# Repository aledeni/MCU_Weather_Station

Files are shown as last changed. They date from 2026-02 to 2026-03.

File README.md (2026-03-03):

# MCU Weather Station

The heart of the board is the ATmega328P microcontroller, it also features a 6-pin AVR-ISP connector for burning the bootloader and a USB connector with serial driver for programming the microcontroller. For connectivity, an ESP8266 Wi-Fi module is provided, connected to the ATmega328P.
The boards were ordered from China via the JLCPCB website (5 pcs at a cost of 31 EUR) and the components will be assembled and soldered by myself.
The board schematic can be found in schematic/MCU_Weather_Station.pdf from this git repository.

__Why this board?__

The purpose of the board is to provide a simple but practical example of an online weather station that will use the api.open-meteo.com server for web requests, weather information such as temperature, humidity and time zone will be shown on the OLED display. I will develop the firmware using Arduino IDE.

__PCB view:__

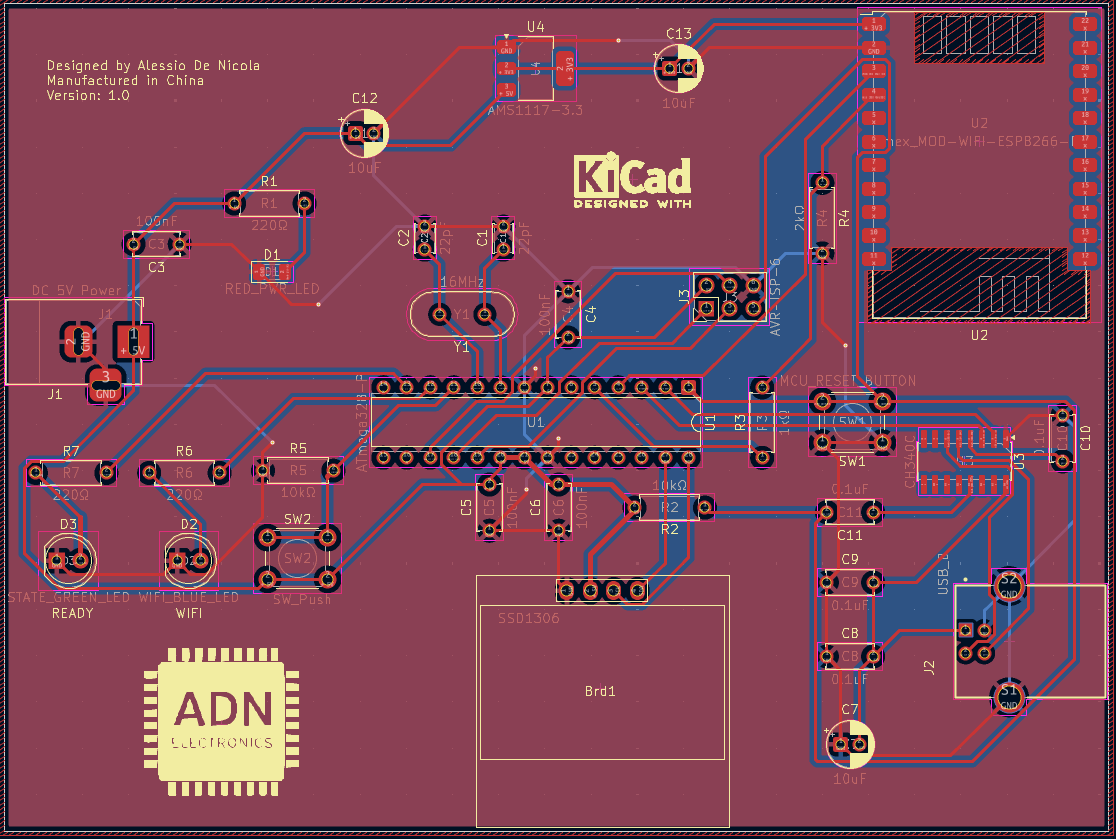
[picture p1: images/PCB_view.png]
PCB view


__3D view:__

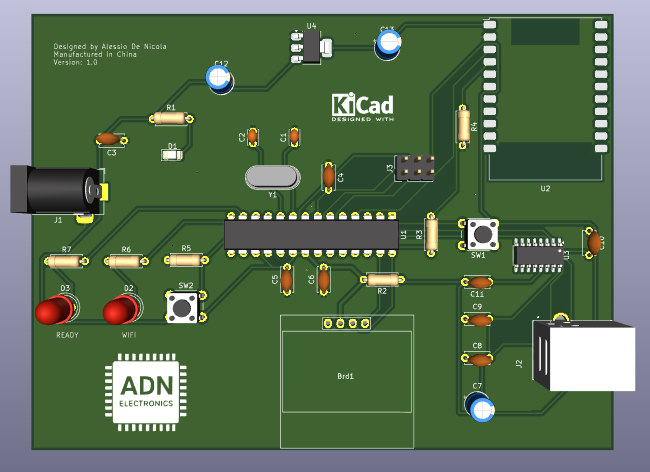
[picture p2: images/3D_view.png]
3D view


__Components:__

- 1x ATmega328P DIP-28
- 1x CH340C serial driver SMD
- 1x ESP8266 Olimex_MOD-WIFI-ESP8266-DEV module
- 1x OLED 128x64 SSD1306 display
- 1x AMS1117 voltage regulator (from 5V to 3.3V)
- 1x USB-B THT connector
- 1x DC Barrel Jack 5V THT
- 1x 16 MHz crystal
- 1x 5mm blue LED
- 1x 5mm green LED
- 1x SMD red power LED
- 2x 6mm THT push buttons
- 1x 2x3 AVR-ISP header
- 7x Resistors THT (3x 220Ω | 2x 10kΩ | 1x 1kΩ | 1x 2kΩ)
- 8x 100nF (0.1uF) ceramic capacitors THT
- 2x 22pF ceramic capacitors THT
- 3x 10uF electrolytic radial capacitors THT

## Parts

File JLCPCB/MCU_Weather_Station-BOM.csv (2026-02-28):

Id | Designator | Footprint | Quantity | Designation | Supplier and ref
1 | C6,C3,C5,C4 | C_Disc_D5.0mm_W2.5mm_P5.00mm | 4 | 100nF
2 | C10,C11,C8,C9 | C_Disc_D5.0mm_W2.5mm_P5.00mm | 4 | 0.1uF
3 | SW1 | SW_PUSH_6mm | 1 | MCU_RESET_BUTTON
4 | J3 | PinHeader_2x03_P2.54mm_Vertical | 1 | AVR-ISP-6
5 | D2 | LED_D5.0mm | 1 | WIFI_BLUE_LED
6 | U3 | SOIC-16_3.9x9.9mm_P1.27mm | 1 | CH340C
7 | R7,R1,R6 | R_Axial_DIN0207_L6.3mm_D2.5mm_P7.62mm_Horizontal | 3 | 220Ω
8 | C13,C7,C12 | CP_Radial_D5.0mm_P2.00mm | 3 | 10uF
9 | U2 | Olimex_MOD-WIFI-ESP8266-DEV | 1 | Olimex_MOD-WIFI-ESP8266-DEV
10 | R2,R5 | R_Axial_DIN0207_L6.3mm_D2.5mm_P7.62mm_Horizontal | 2 | 10kΩ
11 | U1 | DIP-28_W7.62mm | 1 | ATmega328-P
12 | D3 | LED_D5.0mm | 1 | STATE_GREEN_LED
13 | J2 | SAMTEC_USB-B-S-X-X-TH | 1 | USB_B
14 | Y1 | Crystal_HC49-4H_Vertical | 1 | 16MHz
15 | Brd1 | 128x64OLED | 1 | SSD1306
16 | R3 | R_Axial_DIN0207_L6.3mm_D2.5mm_P7.62mm_Horizontal | 1 | 1kΩ
17 | C2,C1 | C_Disc_D3.0mm_W2.0mm_P2.50mm | 2 | 22pF
18 | R4 | R_Axial_DIN0207_L6.3mm_D2.5mm_P7.62mm_Horizontal | 1 | 2kΩ
19 | SW2 | SW_PUSH_6mm | 1 | SW_Push
20 | J1 | BarrelJack_Horizontal | 1 | DC 5V Power
21 | D1 | LED_1206_3216Metric | 1 | RED_PWR_LED
22 | U4 | SOT-223-3_TabPin2 | 1 | AMS1117-3.3

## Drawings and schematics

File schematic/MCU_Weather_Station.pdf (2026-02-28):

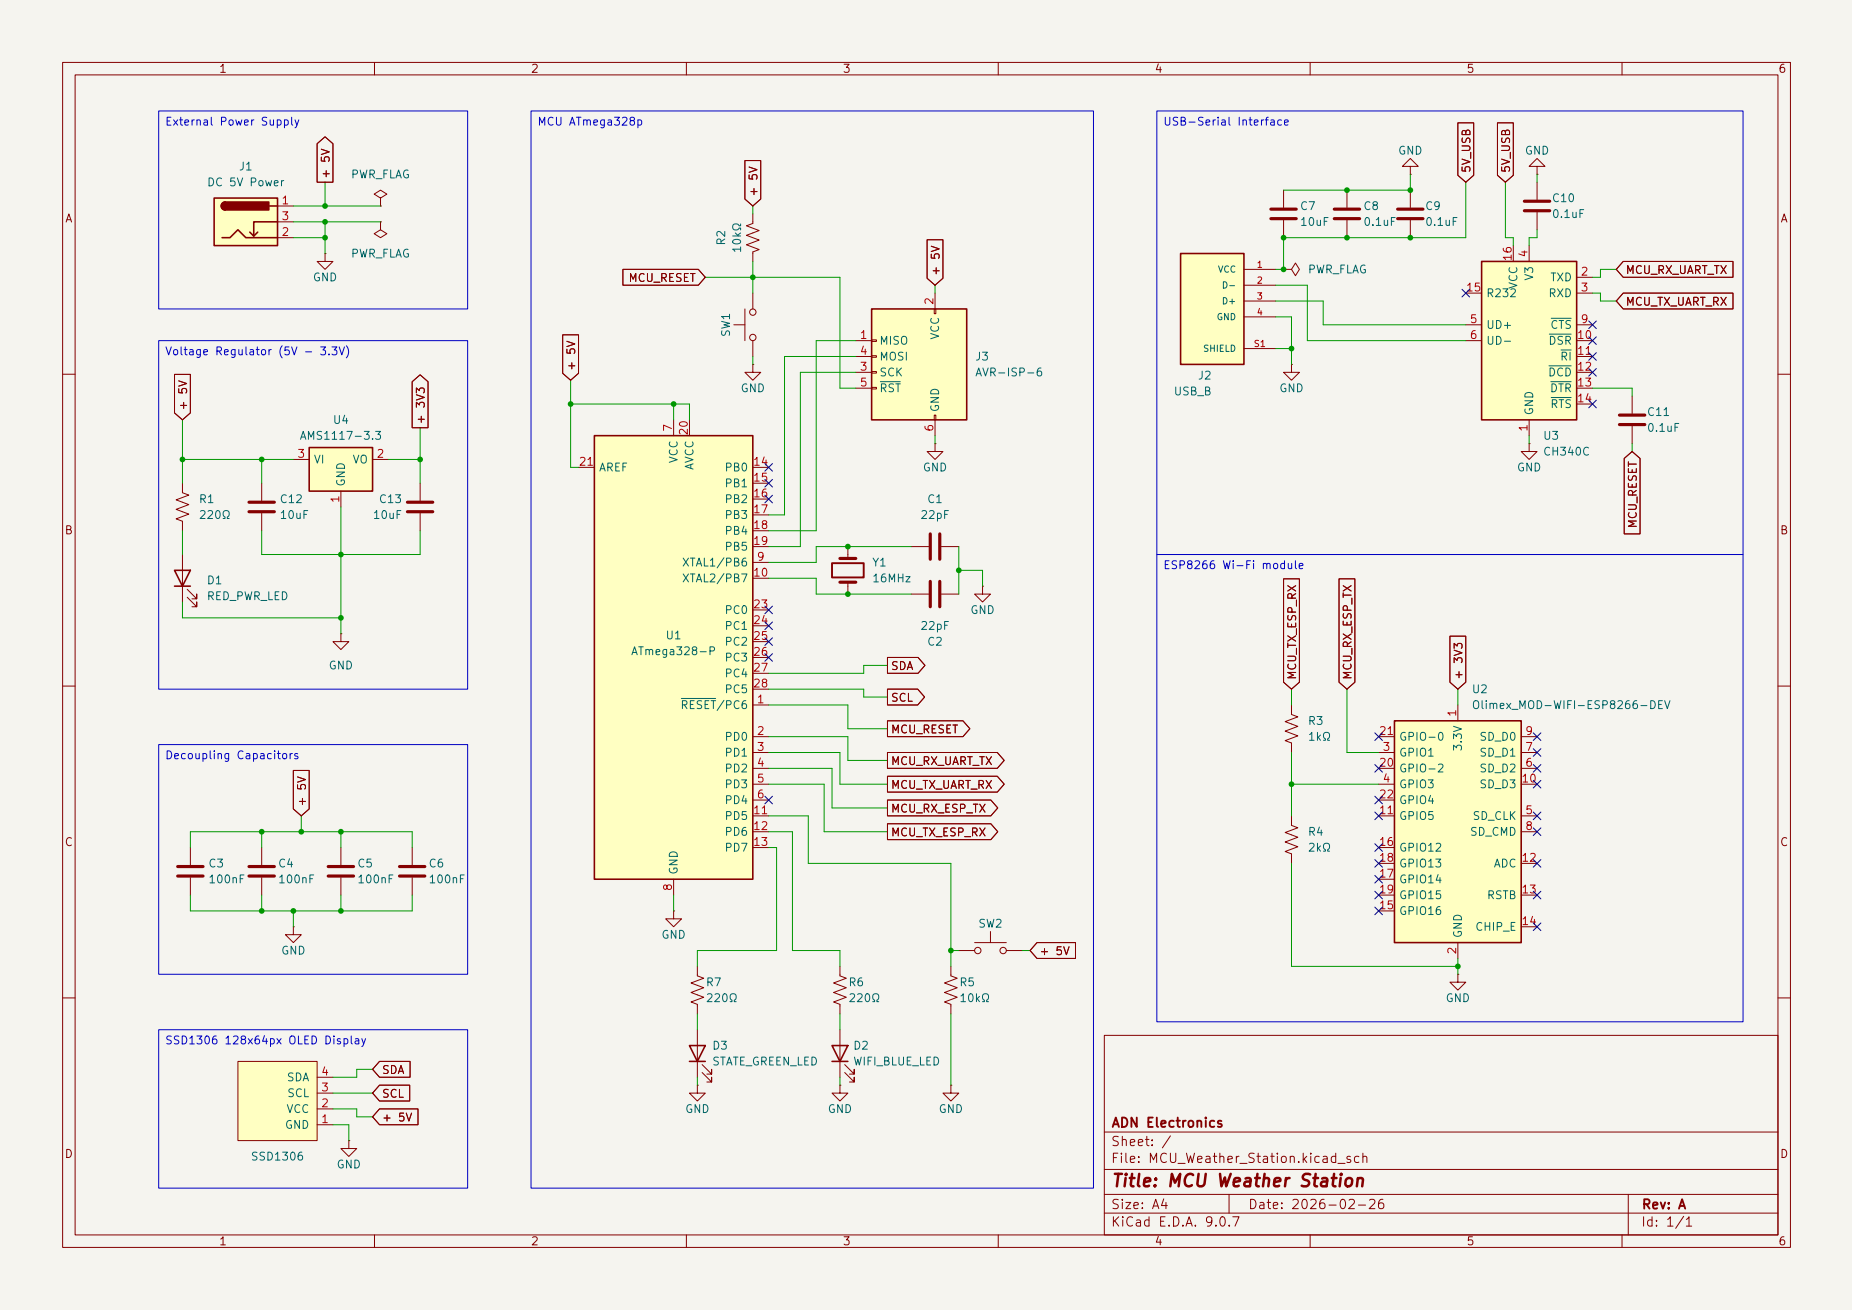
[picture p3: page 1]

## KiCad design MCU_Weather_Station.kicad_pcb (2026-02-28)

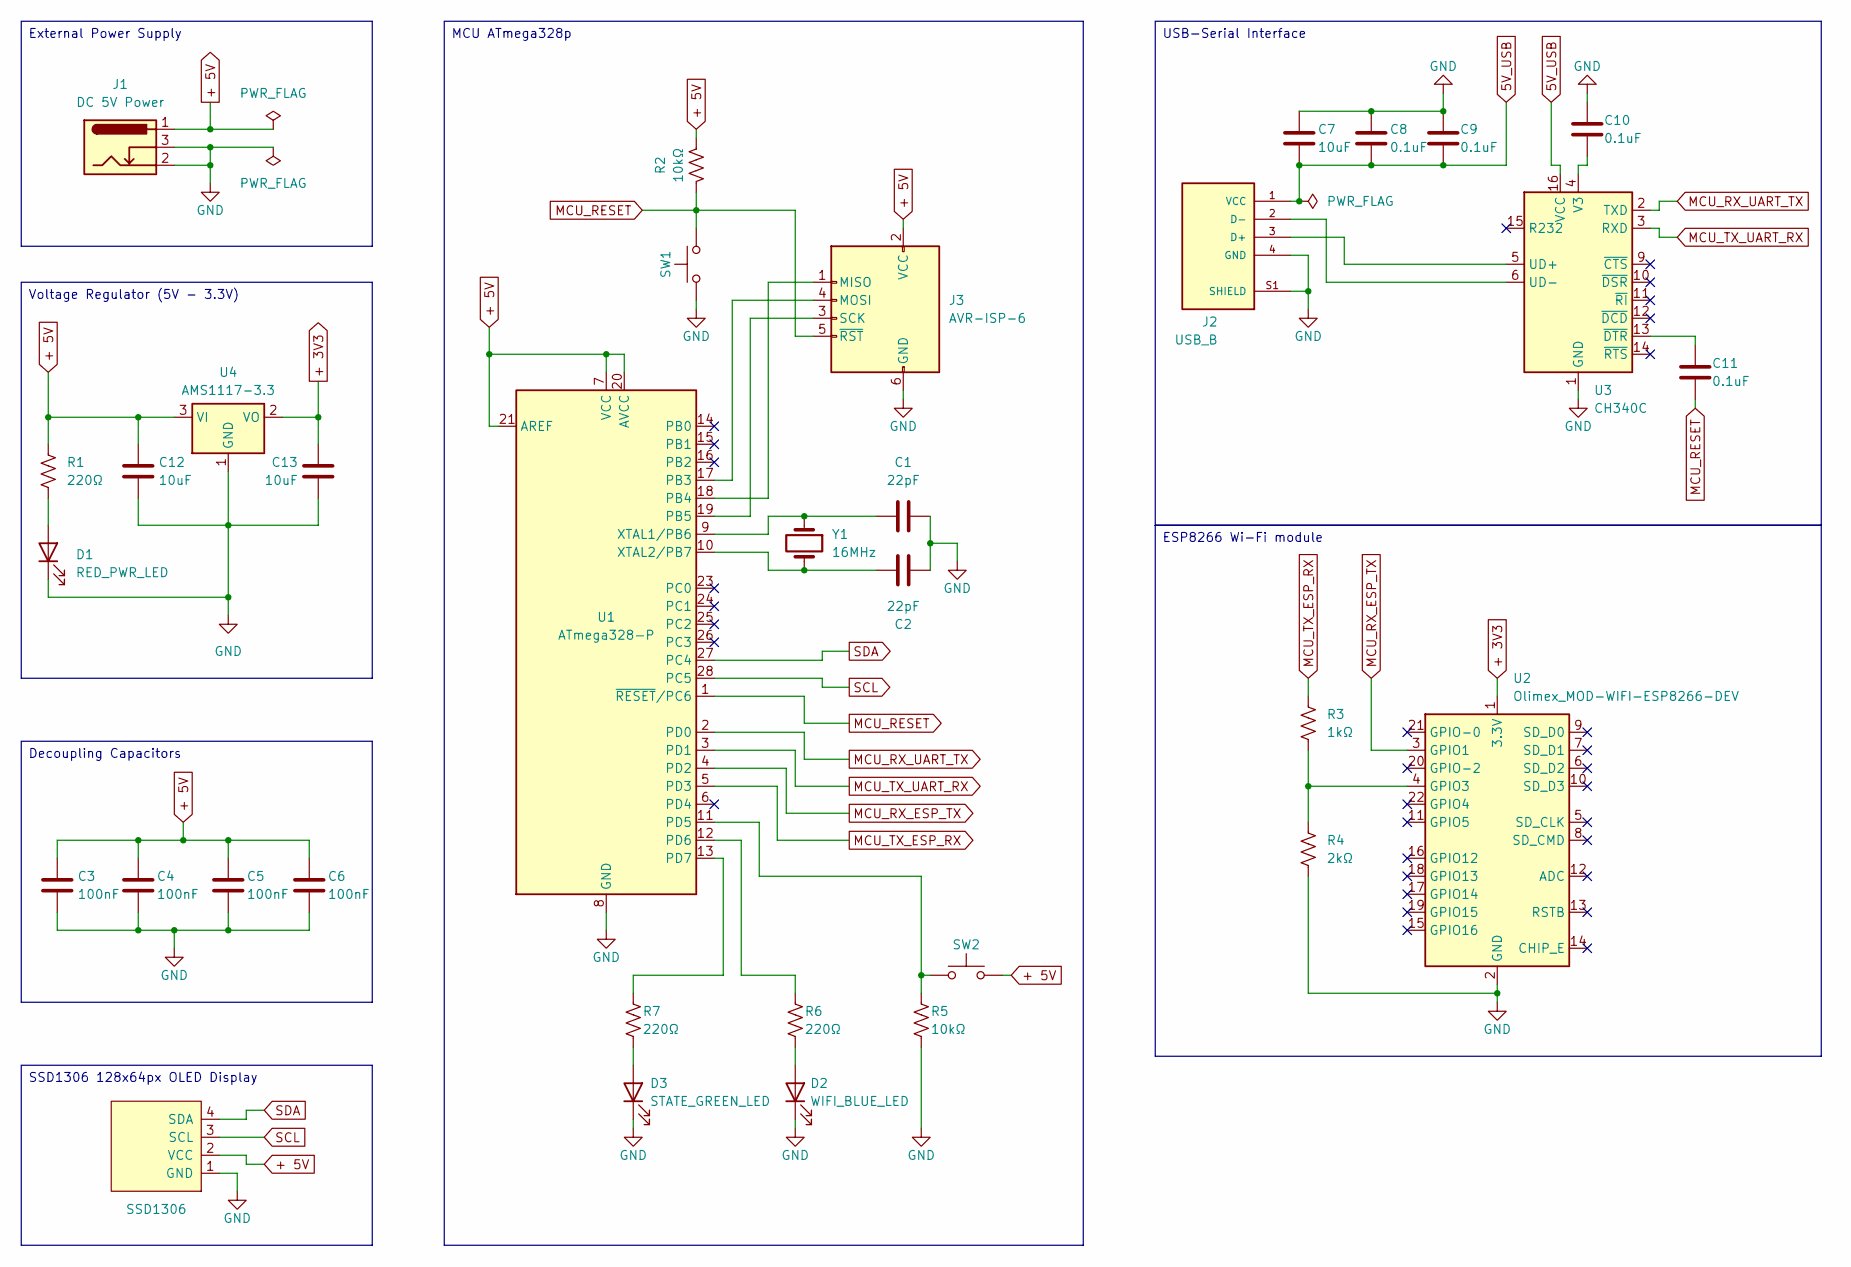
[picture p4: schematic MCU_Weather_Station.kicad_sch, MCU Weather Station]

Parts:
Brd1: SSD1306; 128x64OLED
C1, C2: 22pF; C_Disc_D3.0mm_W2.0mm_P2.50mm
C3, C4, C5, C6: 100nF; C_Disc_D5.0mm_W2.5mm_P5.00mm
C7, C12, C13: 10uF; CP_Radial_D5.0mm_P2.00mm
C8, C9, C10, C11: 0.1uF; C_Disc_D5.0mm_W2.5mm_P5.00mm
D1: RED_PWR_LED; LED_1206_3216Metric
D2: WIFI_BLUE_LED; LED_D5.0mm
D3: STATE_GREEN_LED; LED_D5.0mm
J1: DC 5V Power; BarrelJack_Horizontal
J2: USB_B; SAMTEC_USB-B-S-X-X-TH; PARTREV Q
J3: AVR-ISP-6; PinHeader_2x03_P2.54mm_Vertical
R1, R6, R7: 220Ω; R_Axial_DIN0207_L6.3mm_D2.5mm_P7.62mm_Horizontal
R2, R5: 10kΩ; R_Axial_DIN0207_L6.3mm_D2.5mm_P7.62mm_Horizontal
R3: 1kΩ; R_Axial_DIN0207_L6.3mm_D2.5mm_P7.62mm_Horizontal
R4: 2kΩ; R_Axial_DIN0207_L6.3mm_D2.5mm_P7.62mm_Horizontal
SW1: MCU_RESET_BUTTON; SW_PUSH_6mm
SW2: SW_Push; SW_PUSH_6mm
U1: ATmega328-P; DIP-28_W7.62mm
U2: Olimex_MOD-WIFI-ESP8266-DEV
U3: CH340C; SOIC-16_3.9x9.9mm_P1.27mm
U4: AMS1117-3.3; SOT-223-3_TabPin2
Y1: 16MHz; Crystal_HC49-4H_Vertical

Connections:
5V_USB: C7.2, C8.2, C9.2, J2.1 (VCC), U3.16 (VCC)
+ 3V3: C13.1, U2.1 (3.3V), U4.2 (VO)
+ 5V: Brd1.2 (VCC), C3.2, C4.2, C5.2, C6.2, C12.1, J1.1, J3.2 (VCC), R1.1, R2.2, SW2.2, U1.7 (VCC), U1.20 (AVCC), U1.21 (AREF), U4.3 (VI)
GND: Brd1.1 (GND), C1.2, C2.2, C3.1, C4.1, C5.1, C6.1, C7.1, C8.1, C9.1, C10.1, C12.2, C13.2, D1.1 (K), D2.1 (K), D3.1 (K), J1.2, J1.3, J2.4 (GND), J2.S1 (SHIELD), J2.S2 (SHIELD), J3.6 (GND), R4.2, R5.1, SW1.1, U1.8 (GND), U1.22 (GND), U2.2 (GND), U3.1 (GND), U4.1 (GND)
MCU_RESET: C11.2, J3.5 (~RST), R2.1, SW1.2, U1.1 (~RESET/PC6)
MCU_RX_ESP_TX: U1.4 (PD2), U2.3 (GPIO1)
MCU_RX_UART_TX: U1.2 (PD0), U3.2 (TXD)
MCU_TX_ESP_RX: R3.1, U1.5 (PD3)
MCU_TX_UART_RX: U1.3 (PD1), U3.3 (RXD)
unnamed: D1.2 (A), R1.2
unnamed: D2.2 (A), R6.1
unnamed: D3.2 (A), R7.1
unnamed: J2.3 (D+), U3.5 (UD+)
unnamed: J2.2 (D-), U3.6 (UD-)
unnamed: J3.1 (MISO), U1.18 (PB4)
unnamed: J3.4 (MOSI), U1.17 (PB3)
unnamed: J3.3 (SCK), U1.19 (PB5)
unnamed: R5.2, SW2.1, U1.11 (PD5)
unnamed: R6.2, U1.12 (PD6)
unnamed: R7.2, U1.13 (PD7)
unnamed: C1.1, U1.9 (XTAL1/PB6), Y1.1
unnamed: C2.1, U1.10 (XTAL2/PB7), Y1.2
unnamed: R3.2, R4.1, U2.4 (GPIO3)
unnamed: C10.2, U3.4 (V3)
unnamed: C11.1, U3.13 (~DTR)
SCL: Brd1.3 (SCL), U1.28 (PC5)
SDA: Brd1.4 (SDA), U1.27 (PC4)

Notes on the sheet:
Decoupling Capacitors
USB-Serial Interface
MCU ATmega328p
SSD1306 128x64px OLED Display
ESP8266 Wi-Fi module
External Power Supply
Voltage Regulator (5V - 3.3V)

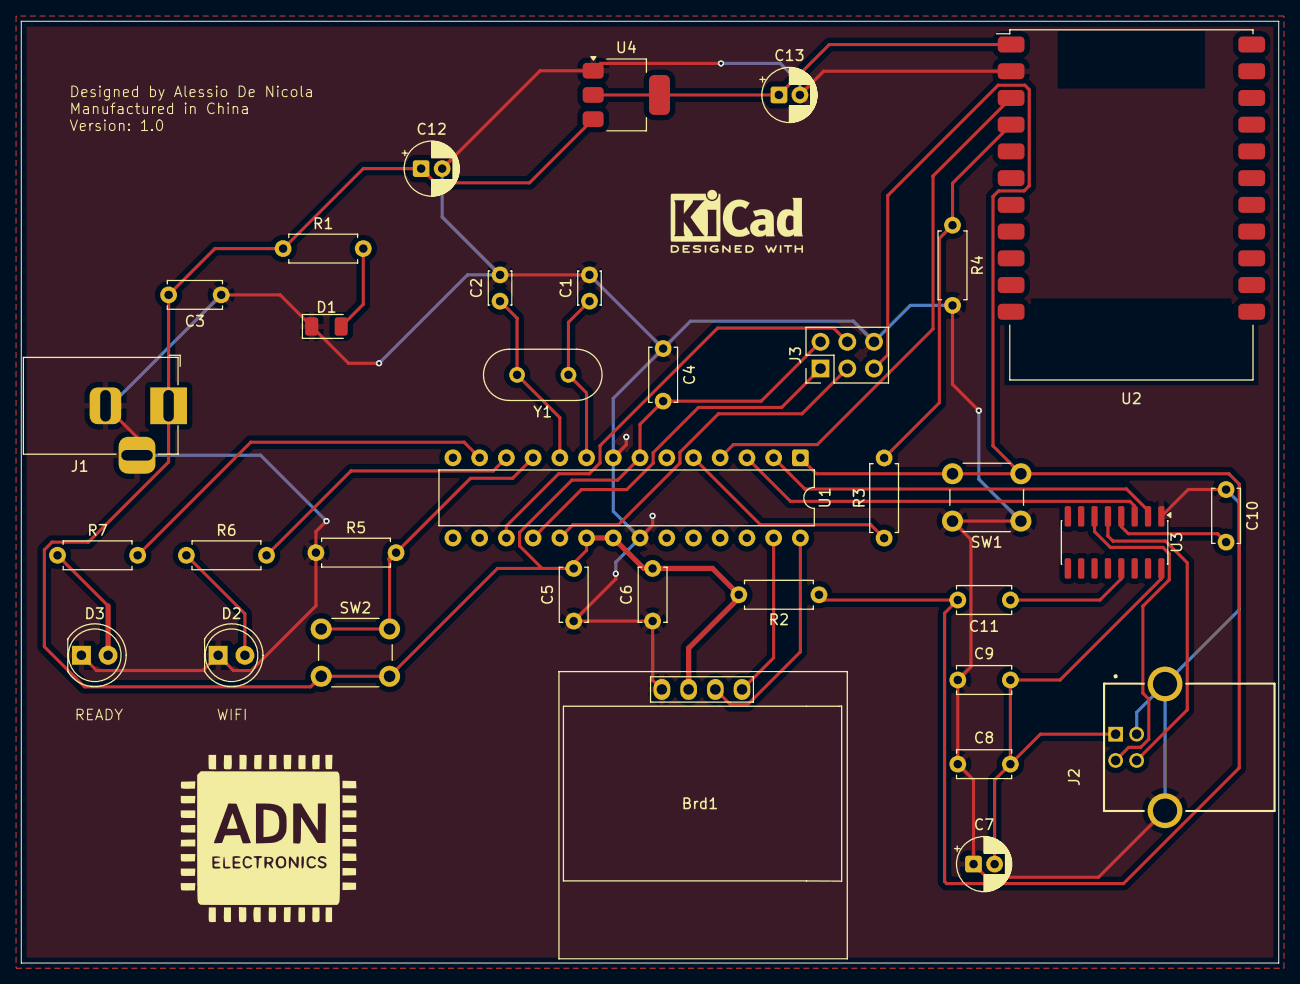
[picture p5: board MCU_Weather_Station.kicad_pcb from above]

Board: 2 copper layers, 119.5 x 89.5 mm, 34 parts (0 on the bottom side), 27 nets.

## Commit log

2026-02-28 Add filled zones (GND front and bottom layer) and resolve all DRC errors
    [MCU_Weather_Station.kicad_pcb]
2026-02-28 Add PCBWay directory for gerber and BOM files to manufacture
    [MCU_Weather_Station.csv, MCU_Weather_Station.kicad_pcb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]
2026-03-01 PCBWay order in state -Subject to audit-
    [MCU_Weather_Station-BOM.csv]
2026-03-02 Pay JLCPCB order
    [MCU_Weather_Station-BOM.csv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]
2026-03-03 Add board images and improve README
2026-03-03 Create schematic directory
